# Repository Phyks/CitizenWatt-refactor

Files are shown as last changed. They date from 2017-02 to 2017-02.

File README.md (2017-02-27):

CitizenWatt-refactor
====================

This is an updated version of [CitizenWatt](http://citizenwatt.paris/) code,
aiming to be a backup of available stuff, with minor updates for anyone
willing to build its own.

CitizenWatt aimed at building a personal DIY energy consumption meter,
inspired by [OpenEnergyMonitor](https://openenergymonitor.org/).

I recently came across cloned CitizenWatt repositories and wanted to make some
lifting of the code, while I set it back in place at home. I also found out
that OpenEnergyMonitor was considerably nicer than it used to be, especially
from a UX point of view. This aims at being an up to date merge of
OpenEnergyMonitor and CitizenWatt, to be the best combination possible at the
moment, in my opinion.

This is part of a home automation process, hence the will to avoid installing
pre-compiled images which are not easily extensible.

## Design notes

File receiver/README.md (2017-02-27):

CitizenWatt-PiBoard
===================

The small piece of PCB to connect the NRF24L01+ to the Pi

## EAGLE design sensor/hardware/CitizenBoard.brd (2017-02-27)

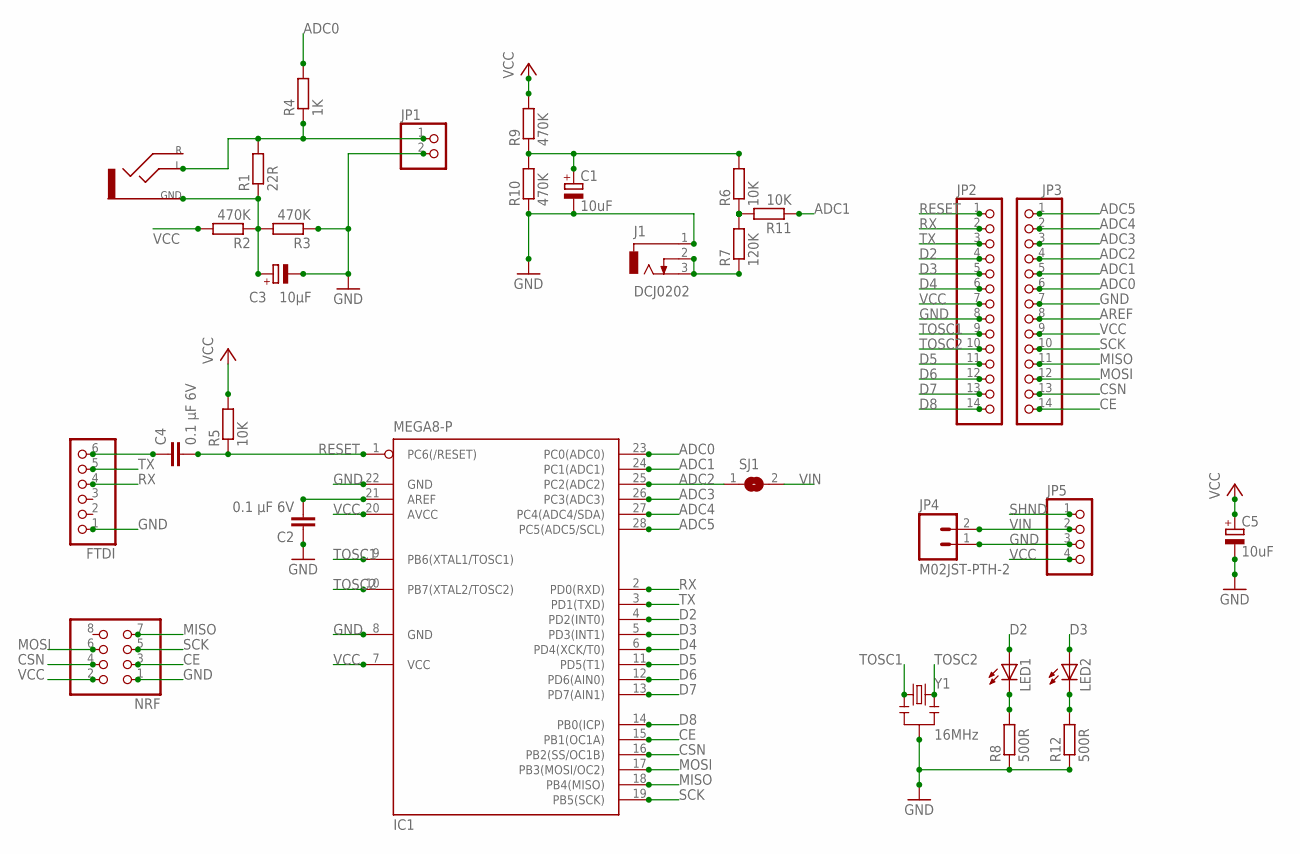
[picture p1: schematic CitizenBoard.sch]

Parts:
C1, C5: 10uF; E2,5-6E
C2, C4: 0.1 µF 6V; C025-024X044
C3: 10µF; E2,5-6E
FTDI: PINHD-1X6; 1X06
IC1: MEGA8-P; DIL28-3
J1: DCJ0202
J2: AUDIO-JACK-3.5
JP1: PINHD-1X2; 1X02
JP2, JP3: PINHD-1X14; 1X14
JP4: M02JST-PTH-2; JST-2-PTH
JP5: PINHD-1X4; 1X04
LED1, LED2: LED3MM
NRF: PINHD-2X4; 2X04
R1: 22R; 0204/7
R2, R3, R9, R10: 470K; 0204/7
R4: 1K; 0204/7
R5, R6, R11: 10K; 0204/7
R7: 120K; 0204/7
R8, R12: 500R; 0204/7
SJ1: SJ
Y1: 16MHz; RESONATOR-PTH

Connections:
ADC0: IC1.23 (PC0(ADC0)), JP3.6, R4.2
ADC1: IC1.24 (PC1(ADC1)), JP3.5, R11.1
ADC2: IC1.25 (PC2(ADC2)), JP3.4, SJ1.1
ADC3: IC1.26 (PC3(ADC3)), JP3.3
ADC4: IC1.27 (PC4(ADC4/SDA)), JP3.2
ADC5: IC1.28 (PC5(ADC5/SCL)), JP3.1
AREF: C2.2, IC1.21 (AREF), JP3.8
CE: IC1.15 (PB1(OC1A)), JP3.14, NRF.3
CSN: IC1.16 (PB2(SS/OC1B)), JP3.13, NRF.4
D2: IC1.4 (PD2(INT0)), JP2.4, LED1.A
D3: IC1.5 (PD3(INT1)), JP2.5, LED2.A
D4: IC1.6 (PD4(XCK/T0)), JP2.6
D5: IC1.11 (PD5(T1)), JP2.11
D6: IC1.12 (PD6(AIN0)), JP2.12
D7: IC1.13 (PD7(AIN1)), JP2.13
D8: IC1.14 (PB0(ICP)), JP2.14
GND: C1.-, C2.1, C3.-, C5.-, FTDI.1, IC1.8 (GND), IC1.22 (GND), J1.1, JP1.2, JP2.8, JP3.7, JP4.1, JP5.3, NRF.1, R3.1, R8.1, R10.1, R12.1, Y1.2
MISO: IC1.18 (PB4(MISO)), JP3.11, NRF.7
MOSI: IC1.17 (PB3(MOSI/OC2)), JP3.12, NRF.6
N: J2.5T (L), JP1.1, R1.2, R4.1
unnamed: R6.1, R7.2, R11.2
unnamed: LED2.K (C), R12.2
unnamed: C4.1, FTDI.6
unnamed: C3.+, J2.1S (GND), R1.1, R2.1, R3.2
unnamed: LED1.K (C), R8.2
unnamed: J1.2, J1.3, R7.1
unnamed: C1.+, R6.2, R9.1, R10.2
RESET: C4.2, IC1.1 (PC6(/RESET)), JP2.1, R5.1
RX: FTDI.4, IC1.2 (PD0(RXD)), JP2.2
SCK: IC1.19 (PB5(SCK)), JP3.10, NRF.5
SHND: JP5.1
TOSC1: IC1.9 (PB6(XTAL1/TOSC1)), JP2.9, Y1.1
TOSC2: IC1.10 (PB7(XTAL2/TOSC2)), JP2.10, Y1.3
TX: FTDI.5, IC1.3 (PD1(TXD)), JP2.3
VCC: C5.+, IC1.7 (VCC), IC1.20 (AVCC), JP2.7, JP3.9, JP5.4, NRF.2, R2.2, R5.2, R9.2
VIN: JP4.2, JP5.2, SJ1.2

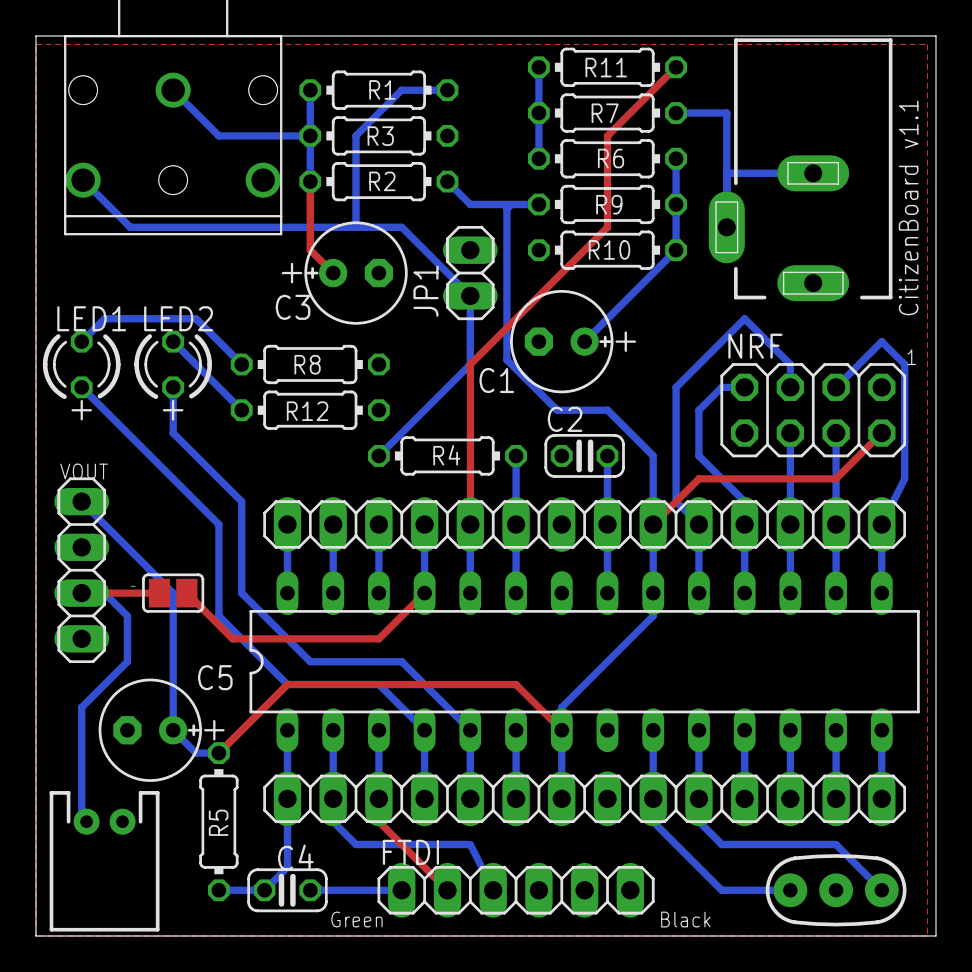
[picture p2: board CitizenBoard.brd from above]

Board: 2 copper layers, 50.0 x 50.0 mm, 31 parts (0 on the bottom side), 35 nets.

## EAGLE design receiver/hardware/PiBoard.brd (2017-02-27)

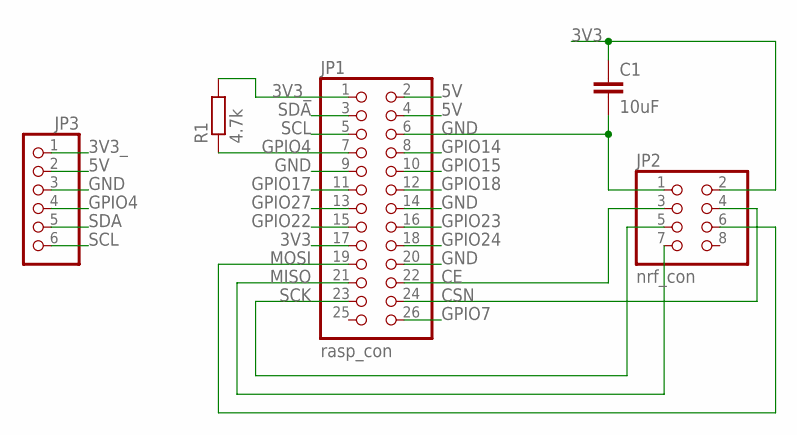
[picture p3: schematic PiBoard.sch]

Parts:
C1: 10uF; 1206
JP1: rasp_con; 2X13
JP2: nrf_con; 2X04
JP3: PINHD-1X6; 1X06
R1: 4.7k; R1206

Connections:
3V3: C1.1, JP1.17, JP2.2
3V3_: JP1.1, JP3.1, R1.2
5V: JP1.2, JP1.4, JP3.2
CE: JP1.22, JP2.3
CSN: JP1.24, JP2.4
GND: C1.2, JP1.6, JP1.9, JP1.14, JP1.20, JP2.1, JP3.3
GPIO4: JP1.7, JP3.4, R1.1
GPIO7: JP1.26
GPIO14: JP1.8
GPIO15: JP1.10
GPIO17: JP1.11
GPIO18: JP1.12
GPIO22: JP1.15
GPIO23: JP1.16
GPIO24: JP1.18
GPIO27: JP1.13
MISO: JP1.21, JP2.7
MOSI: JP1.19, JP2.6
SCK: JP1.23, JP2.5
SCL: JP1.5, JP3.6
SDA: JP1.3, JP3.5

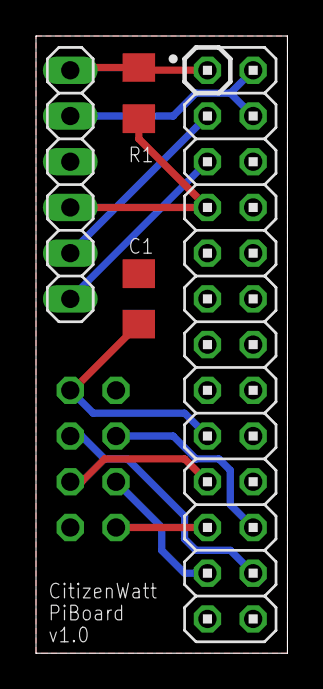
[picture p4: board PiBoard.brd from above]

Board: 2 copper layers, 14.0 x 34.3 mm, 5 parts (1 on the bottom side), 12 nets.

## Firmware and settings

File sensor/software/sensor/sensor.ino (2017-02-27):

 ///////////////////
//   Includes    //
///////////////////

#include <EEPROM.h>
#include <SPI.h>
#include <avr/sleep.h>
#include <avr/power.h>
#include <nRF24L01.h>
#include <RF24.h>      // https://github.com/stanleyseow/RF24/tree/2a1a4e6e27056844a3bc419d65b8a2d4e0f1770e
#include "printf.h"
#include <EmonLib.h>   // https://github.com/openenergymonitor/EmonLib
#include <AESLib.h>    // https://github.com/DavyLandman/AESLib

///////////////////////
//   CONFIGURATION   //
///////////////////////

#define DEBUG 1
#define SERIAL_BAUDRATE 57600

// PreAmplifier level for the nRF
// Lower this to reduce power consumption. This will reduce range.
rf24_pa_dbm_e NRF_PA_LEVEL = RF24_PA_LOW;

// Radio pipe addresses for the 2 nodes to communicate.
uint64_t pipes[2] = { 0xE056D446D0LL, 0xF0F0F0F0D2LL };

// AES
uint8_t key[] = {0,1,2,3,4,5,6,7,8,9,10,11,12,13,14,15};

// Calibration factor for the intensity
double ICAL = 85.0;

// =============================================================

// Speed for the nrf module
// RF24_250KBPS / RF24_1MBPS / RF24_2MBPS
// Reduce it to improve reliability
rf24_datarate_e NRF_SPEED = RF24_250KBPS;

// Channel for the nrf module
// 76 is default safe channel in RF24
int NRF_CHANNEL = 0x4c;

// Set this to 0 to enable voltage measurement.
// Else, set this to your mean voltage.
double VOLTAGE = 240.0;

// Number of samples over which the mean must be done for the current measurement
int NUMBER_SAMPLES_I = 1480;

// Pin for current measurement
const int CURRENT_PIN = A0;

// Pin for voltage measurement
const int VOLTAGE_PIN = 0;

// Pin for the green LED
const int GREEN_LED_PIN = 2;

// Pin for the red LED
const int RED_LED_PIN = 3;

// Energy Monitor object
EnergyMonitor emon1;

///////////////////////
//   Declarations    //
///////////////////////

#define TIMEOUT 250 // timeout in ms

// Struct to send RF data
typedef struct {
    int power;
    int voltage;
    int battery;
    unsigned long timer;
    long padding4;
    int padding2;
} PayloadTX;

// Next measurement to be sent
PayloadTX nrf = {0, 0, 0, 0, 0, 0};

////////////////////////////////
//   Hardware configuration   //
////////////////////////////////

// Set up nRF24L01 radio on SPI bus plus pins 9 & 10
RF24 radio(9,10);

//////////////////////////////
//   Sleep configuration    //
//////////////////////////////

typedef enum { wdt_16ms = 0, wdt_32ms, wdt_64ms, wdt_128ms, wdt_250ms, wdt_500ms, wdt_1s, wdt_2s, wdt_4s, wdt_8s } wdt_prescalar_e;

void setup_watchdog(uint8_t prescalar);
void do_sleep(void);

//////////////////////////
//   Setup operation    //
//////////////////////////

void setup(void)
{
  pinMode(RED_LED_PIN, OUTPUT);
  pinMode(GREEN_LED_PIN, OUTPUT);
  digitalWrite(RED_LED_PIN, HIGH);
  digitalWrite(GREEN_LED_PIN, HIGH);
  
  
  Serial.begin(SERIAL_BAUDRATE);
  Serial.println(F("/!\\ STARTING CitizenWatt Sensor"));
  Serial.println(F("//////////////////////////////"));
  Serial.println(F("//    CitizenWatt sensor    //"));
  Serial.println(F("//    citizenwatt.paris     //"));
  Serial.println(F("////////////////////////////// \n"));

  if( DEBUG )
    printf_begin();

  //
  // Prepare sleep parameters
  //

  setup_watchdog(wdt_8s); // /!\ 8s sleeping

  //
  // Setup and configure rf radio
  //

  // Initialize nRF
  radio.begin();
  radio.setChannel(NRF_CHANNEL);

  // Max number of retries and max delay between them
  radio.setRetries(15, 15);

  // Reduce payload size to improve reliability
  radio.setPayloadSize(16);

  // Set the datarate
  radio.setDataRate(NRF_SPEED);

  // Use the largest CRC
  radio.setCRCLength(RF24_CRC_16);

  // Ensure auto ACK is enabled
  //radio.setAutoAck(1);

  // Use the adapted PA level
  radio.setPALevel(NRF_PA_LEVEL);

  // Open writing pipe
  radio.openWritingPipe(pipes[0]);
  radio.openReadingPipe(1, pipes[1]);

  if(DEBUG) {
    radio.printDetails();
  }
  
  // Init EnergyMonitor, with calibration factor for R1 = 22 Ohms
  emon1.current(0, ICAL);

  digitalWrite(RED_LED_PIN, LOW);
  digitalWrite(GREEN_LED_PIN, LOW);
}

///////////////////////////////
//   Loop part of the code   //
///////////////////////////////

void loop(void)
{
  //
  // Read Current
  //
  digitalWrite(GREEN_LED_PIN, HIGH);
  nrf.power = (int) (emon1.calcIrms(NUMBER_SAMPLES_I) * VOLTAGE);
  digitalWrite(GREEN_LED_PIN, LOW);
  
  // Set voltage
  nrf.voltage = VOLTAGE;
  
  // Read Vcc
  nrf.battery = (int) emon1.readVcc();
  
  // Adding random for AES
  nrf.timer = millis();
  
  if( DEBUG )
  {
    Serial.print("|");
    Serial.print(nrf.power);
    Serial.print("\t");
    Serial.print("|");
    Serial.print("\t");
    Serial.print(nrf.voltage);
    Serial.print("\t");
    Serial.print("|");
    Serial.print("\t");
    Serial.print(nrf.battery);
    Serial.print("\t");
    Serial.println("|");
    
    Serial.print(F("Clear :"));      
    PrintHex8((uint8_t*)&nrf, sizeof(PayloadTX));
    Serial.println();
    Serial.flush();
  }
  
  // AES ciphering
  aes128_enc_single(key, &nrf);
  
  if( DEBUG )
  {
    Serial.print(F("Cipher:"));      
    PrintHex8((uint8_t*)&nrf, sizeof(PayloadTX));
    Serial.println();
    Serial.flush();
  }
    
  //
  // Data sender
  //

  // First, stop listening so we can talk.
  radio.stopListening();
       
  radio.write(&nrf, sizeof(PayloadTX));

  // Now, continue listening now the goal is to get some data back as ACK
  radio.startListening();

  // Wait here until we get a response, or timeout (250ms)
  unsigned long started_waiting_at = millis();
  bool timeout = false;
  while ( ! radio.available() && ! timeout )
    if (millis() - started_waiting_at > TIMEOUT )
      timeout = true;

  // Describe the results
  if ( timeout && DEBUG )
    Serial.println(F("[!] Failed to send packet : response timed out ..."));
  
  // Stop listening
  radio.stopListening();
    
  //
  // Shut down the system
  //

  // 100ms for the MCU to settle 
  delay(100);

  // Power down the radio.  Note that the radio will get powered back up
  // on the next write() call.
  // TODO : Fix this !
  //radio.powerDown();

  // Sleep the MCU.  The watchdog timer will awaken in a short while, and
  // continue execution here.
  do_sleep();
  
  // 100ms for the MCU to settle 
  delay(100);
  
}

//////////////////////////
//   Sleep functions    //
//////////////////////////

// 0=16ms, 1=32ms,2=64ms,3=125ms,4=250ms,5=500ms
// 6=1 sec,7=2 sec, 8=4 sec, 9= 8sec

void setup_watchdog(uint8_t prescalar)
{
  prescalar = min(9,prescalar);
  uint8_t wdtcsr = prescalar & 7;
  if ( prescalar & 8 )
    wdtcsr |= _BV(WDP3);

  MCUSR &= ~_BV(WDRF);
  WDTCSR = _BV(WDCE) | _BV(WDE);
  WDTCSR = _BV(WDCE) | wdtcsr | _BV(WDIE);
}

ISR(WDT_vect)
{
}

void do_sleep(void)
{
  set_sleep_mode(SLEEP_MODE_PWR_DOWN); // sleep mode is set here
  sleep_enable();

  sleep_mode();                        // System sleeps here

  sleep_disable();                     // System continues execution here when watchdog timed out
}

// Function for debug
void PrintHex8(uint8_t *data, uint8_t length) // prints 8-bit data in hex with leading zeroes
{
  Serial.print("0x"); 
  for (int i=0; i<length; i++) { 
    if (data[i]<0x10) {Serial.print("0");} 
    Serial.print(data[i],HEX); 
    Serial.print(" "); 
  }
}

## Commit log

2017-02-27 Reimport projects into this one
    [CitizenBoard.brd, CitizenBoard.sch, PiBoard.brd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]
2017-02-27 Move stuff around
    [CitizenBoard.brd, CitizenBoard.sch, PiBoard.brd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]

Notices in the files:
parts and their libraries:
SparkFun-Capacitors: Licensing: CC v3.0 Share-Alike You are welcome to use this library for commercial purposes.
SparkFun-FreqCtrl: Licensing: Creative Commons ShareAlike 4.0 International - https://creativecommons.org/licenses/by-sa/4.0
